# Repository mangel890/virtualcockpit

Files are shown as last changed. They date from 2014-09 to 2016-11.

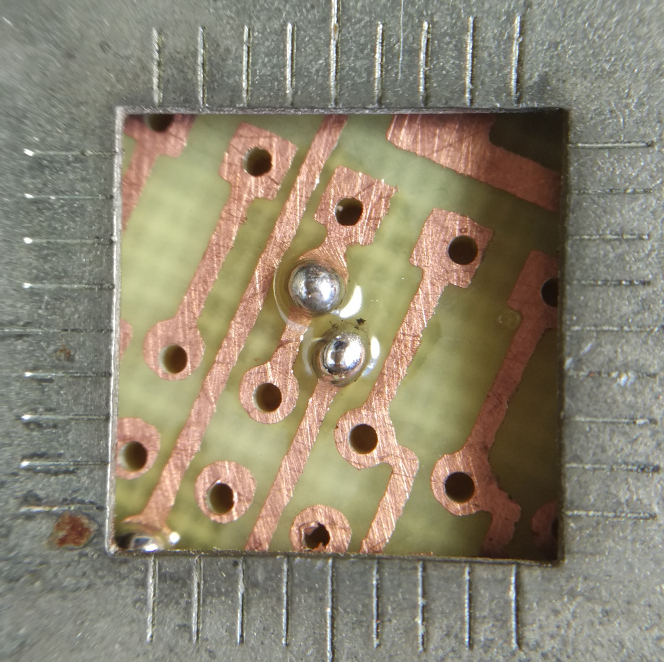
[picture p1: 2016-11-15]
images/ard4.jpg

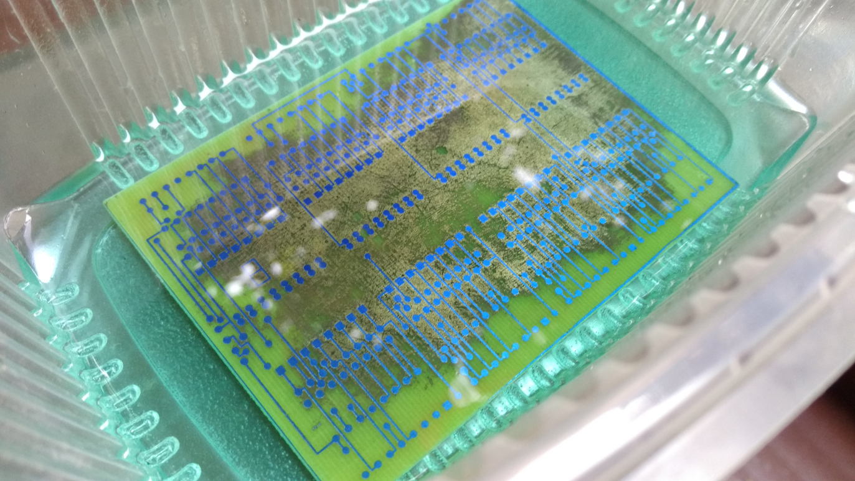
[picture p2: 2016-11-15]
images/ard2.jpg

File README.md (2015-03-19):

# virtualcockpit
Virtual Boeing 737 Cockpit

This is a project to build my own Boeing 737 cockpit
It is based on Arduino and Flight Simulator

This is on early stages now, many more changes are needed

Arduino/ contains a arduino .ino file for the MCP of the 737

CNC/ Sketch developed for my CNC that helps drilling the panels

PCB/ Different boards developed for extending input and output in Arduino Mega

Drawings/ Sketch developed for printing the MCP of the 737

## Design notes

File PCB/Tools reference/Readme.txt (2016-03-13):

Use Inkscape
Save in .dxf unchecking ROBO-Master and LWPolyline output types
Open file in DXF2GCODE: https://sourceforge.net/projects/dxf2gcode/?source=typ_redirect
Export: Optimize and convert (make sure you modify the z levels so that it only mills at one level)
Open in Basic3DViewer

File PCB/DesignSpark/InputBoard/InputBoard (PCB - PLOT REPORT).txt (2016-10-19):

PLOT REPORT
-----------

Report File:        C:\repo\PCB\DesignSpark\InputBoard\InputBoard (PCB - PLOT REPORT).txt
Report Written:     Wednesday, October 19, 2016
Project Path:       C:\repo\PCB\DesignSpark\InputBoard\InputBoard.prj
Design Path:        C:\repo\PCB\DesignSpark\InputBoard\InputBoard.pcb
Design Title:       
Created:            28/03/2015 19:30:17
Last Saved:         19/10/2016 20:01:03
Editing Time:       784 min
Units:              mm (precision 1)

Device Settings
===============

Windows Settings
================

    Printer 'Bullzip PDF Printer'
    Copies: 1

Plots Output
============

    Plot Job: "C:\repo\PCB\DesignSpark\InputBoard\InputBoard.mop"

Windows Output
==============

    Layers:
    -----------------
    Bottom Copper

End Of Report.

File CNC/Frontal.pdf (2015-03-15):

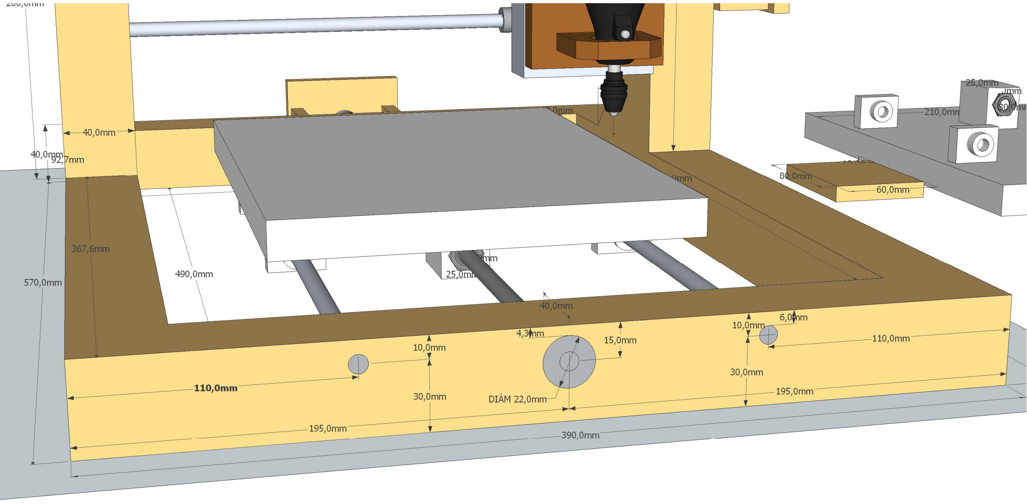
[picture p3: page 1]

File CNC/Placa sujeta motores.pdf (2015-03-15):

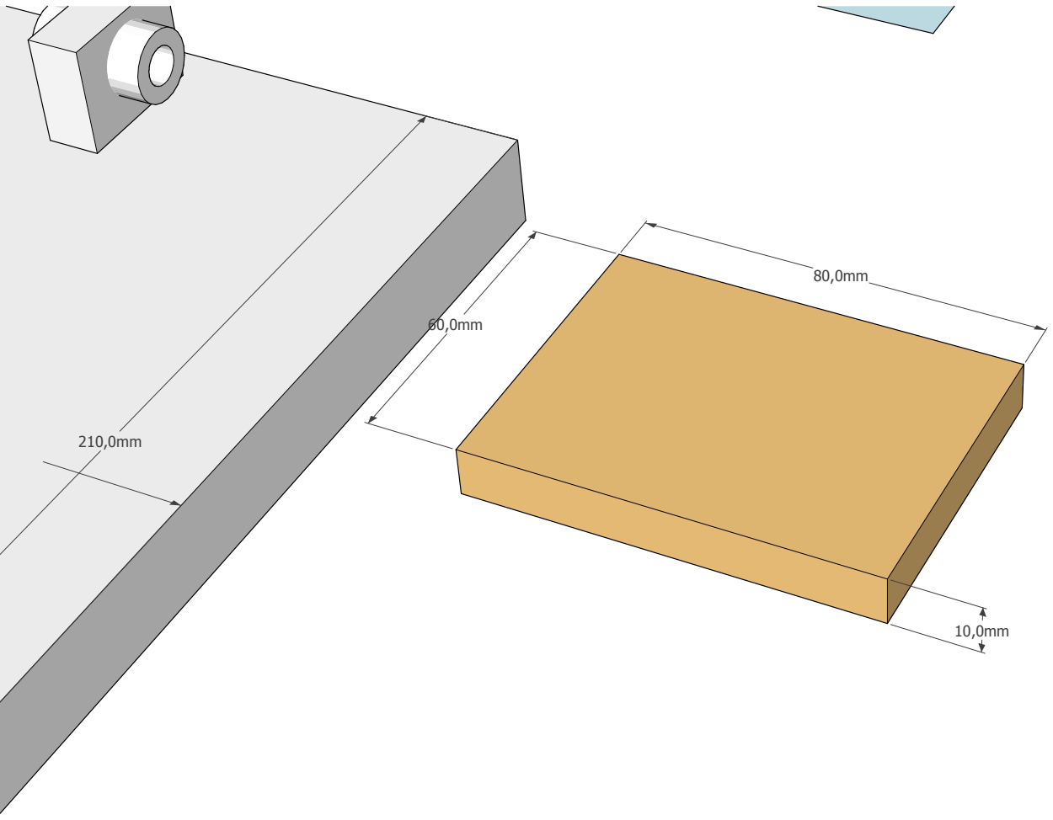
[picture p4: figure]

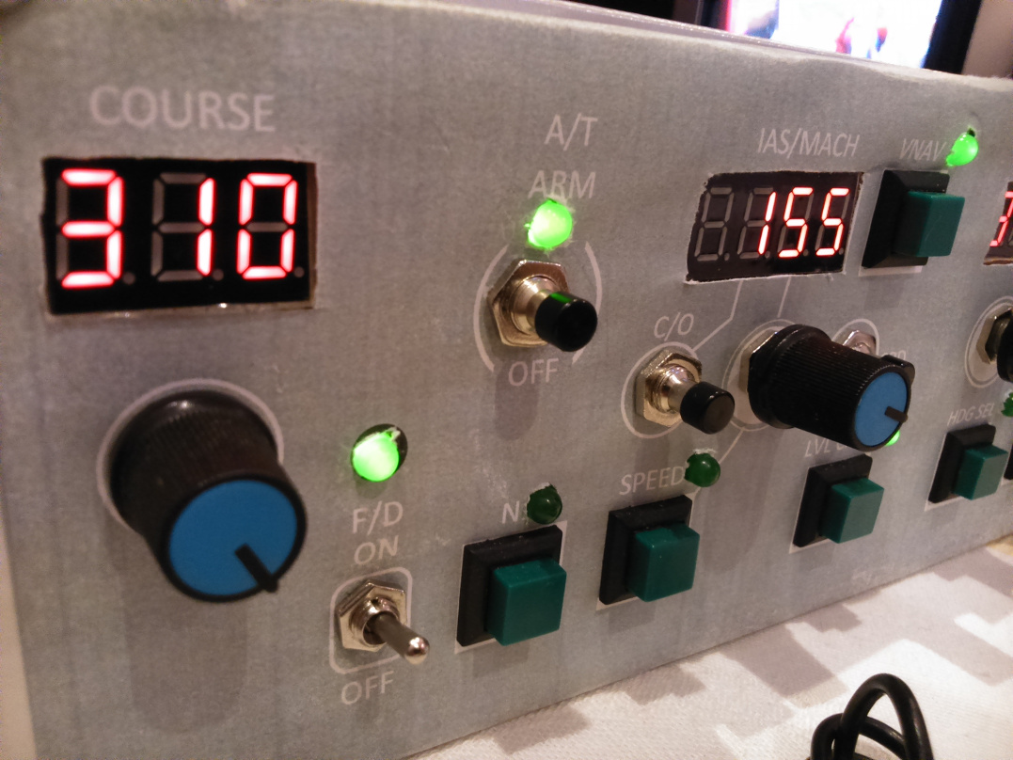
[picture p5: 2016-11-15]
images/mcp1.jpg

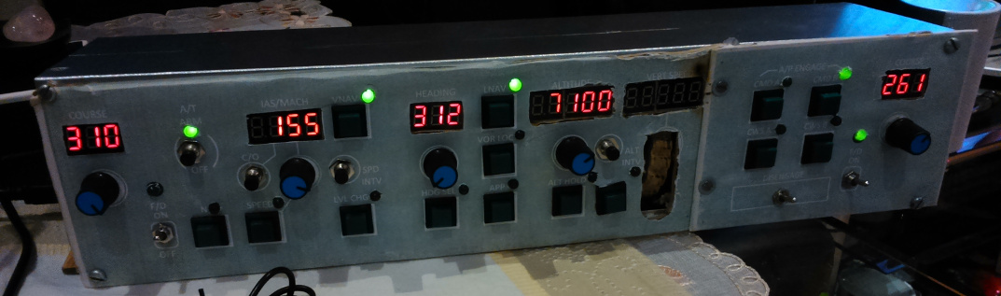
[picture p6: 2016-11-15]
images/mcp3.jpg

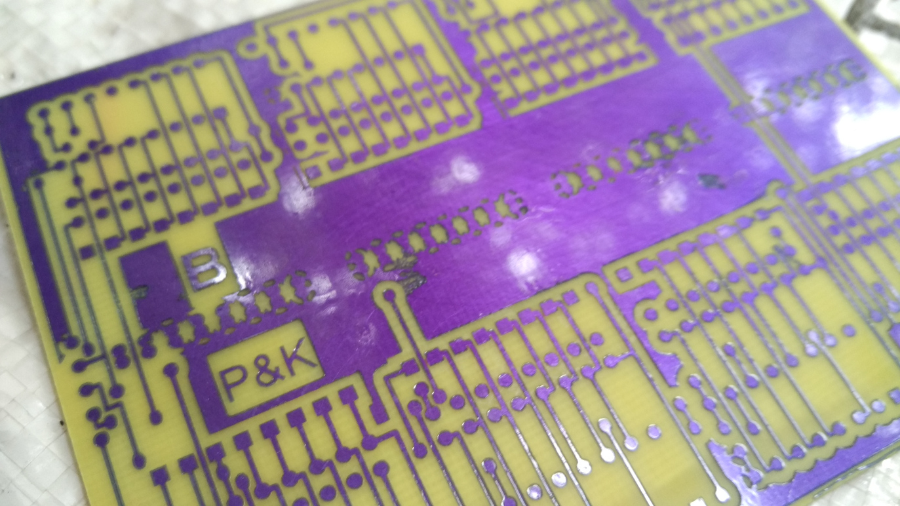
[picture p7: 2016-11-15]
images/ard3.jpg

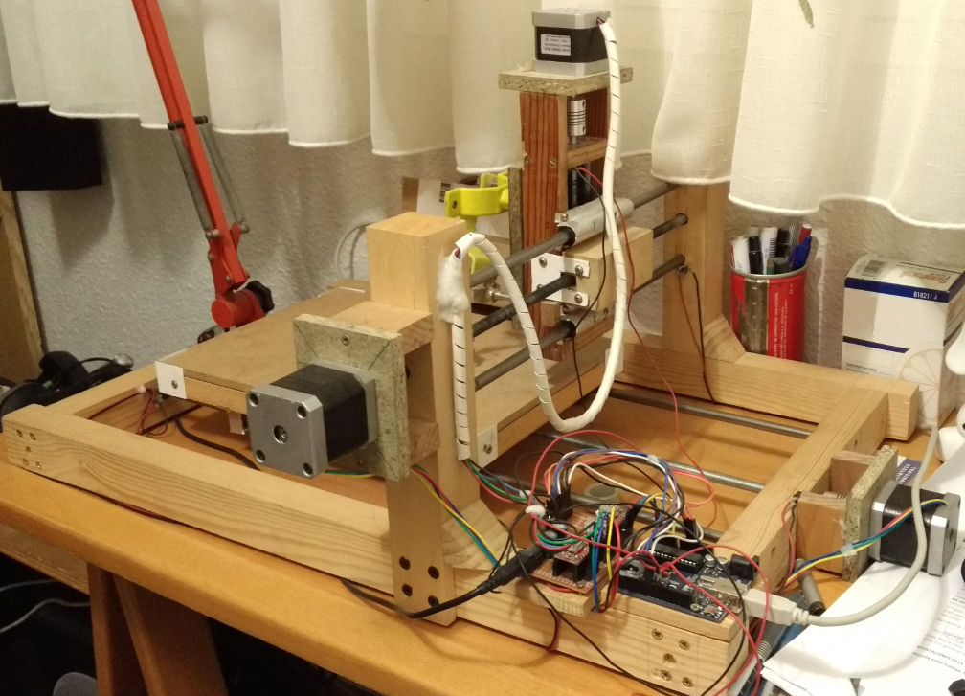
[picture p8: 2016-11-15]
images/cnc1.jpg

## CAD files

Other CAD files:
CNC/Sketch.skp

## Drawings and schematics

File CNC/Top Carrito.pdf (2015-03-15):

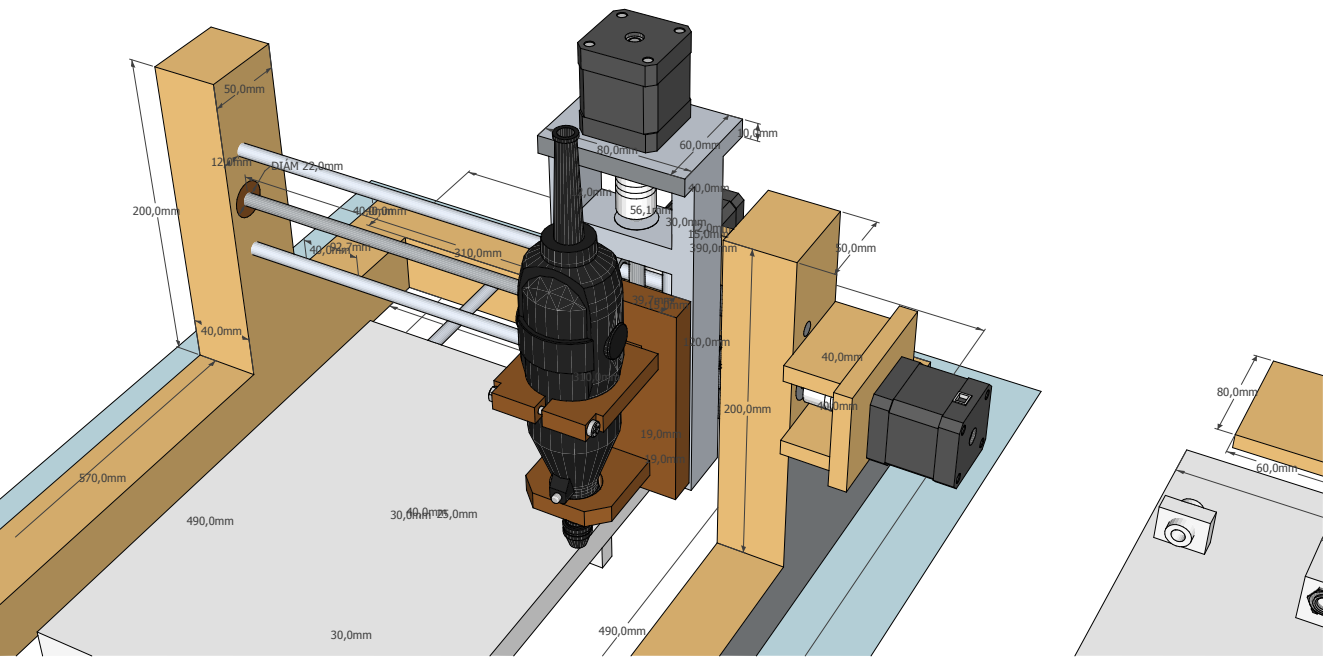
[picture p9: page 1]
DIÁM 22,0mm

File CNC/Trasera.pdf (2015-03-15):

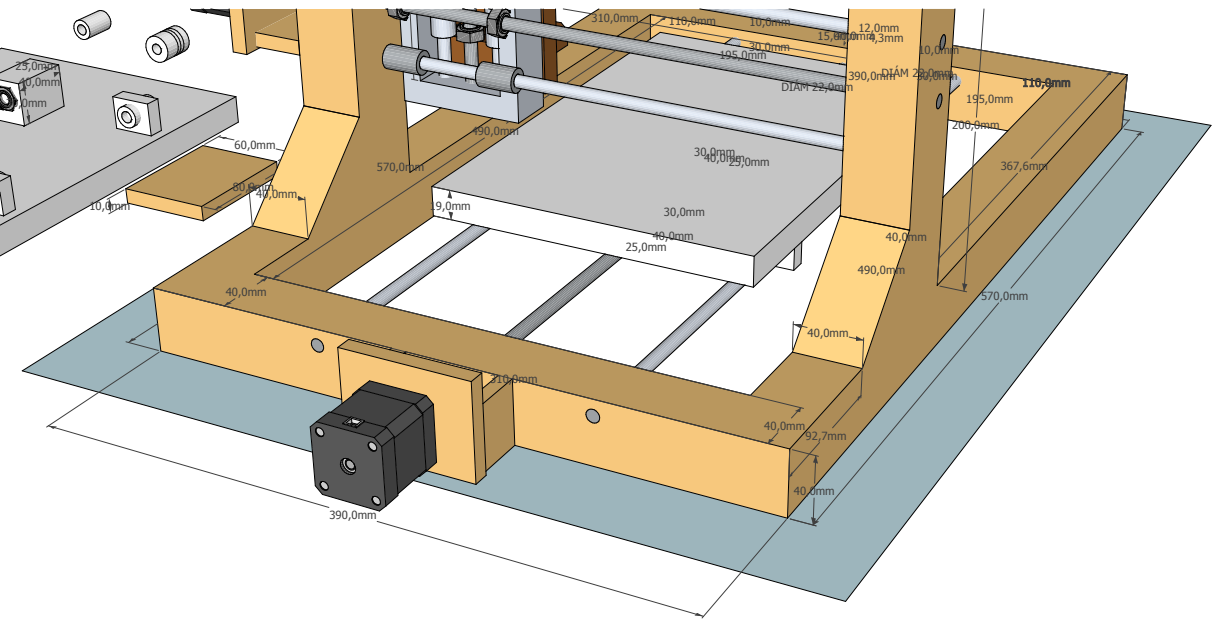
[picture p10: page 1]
DIÁM 22,0mm

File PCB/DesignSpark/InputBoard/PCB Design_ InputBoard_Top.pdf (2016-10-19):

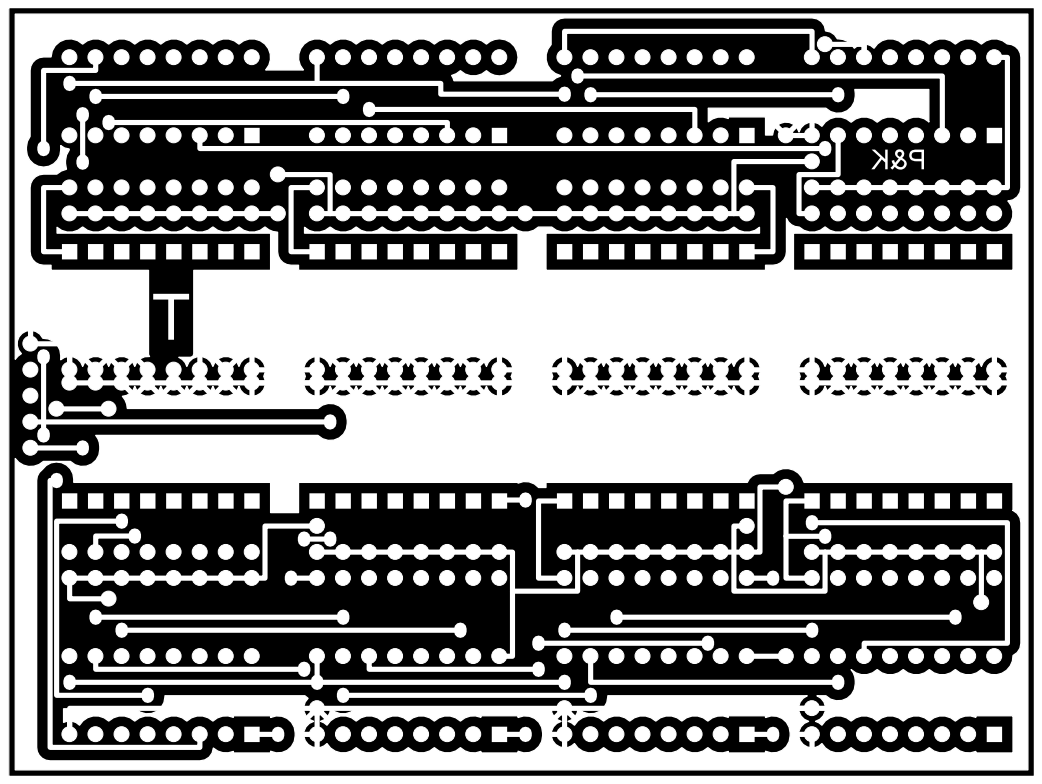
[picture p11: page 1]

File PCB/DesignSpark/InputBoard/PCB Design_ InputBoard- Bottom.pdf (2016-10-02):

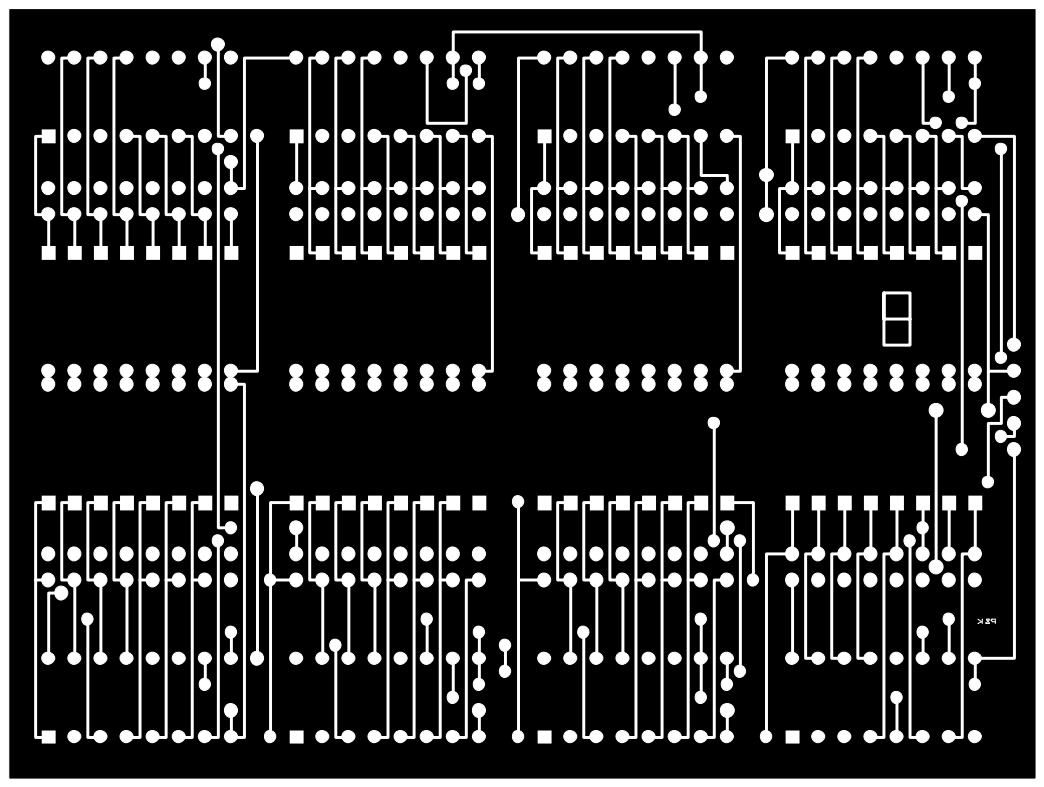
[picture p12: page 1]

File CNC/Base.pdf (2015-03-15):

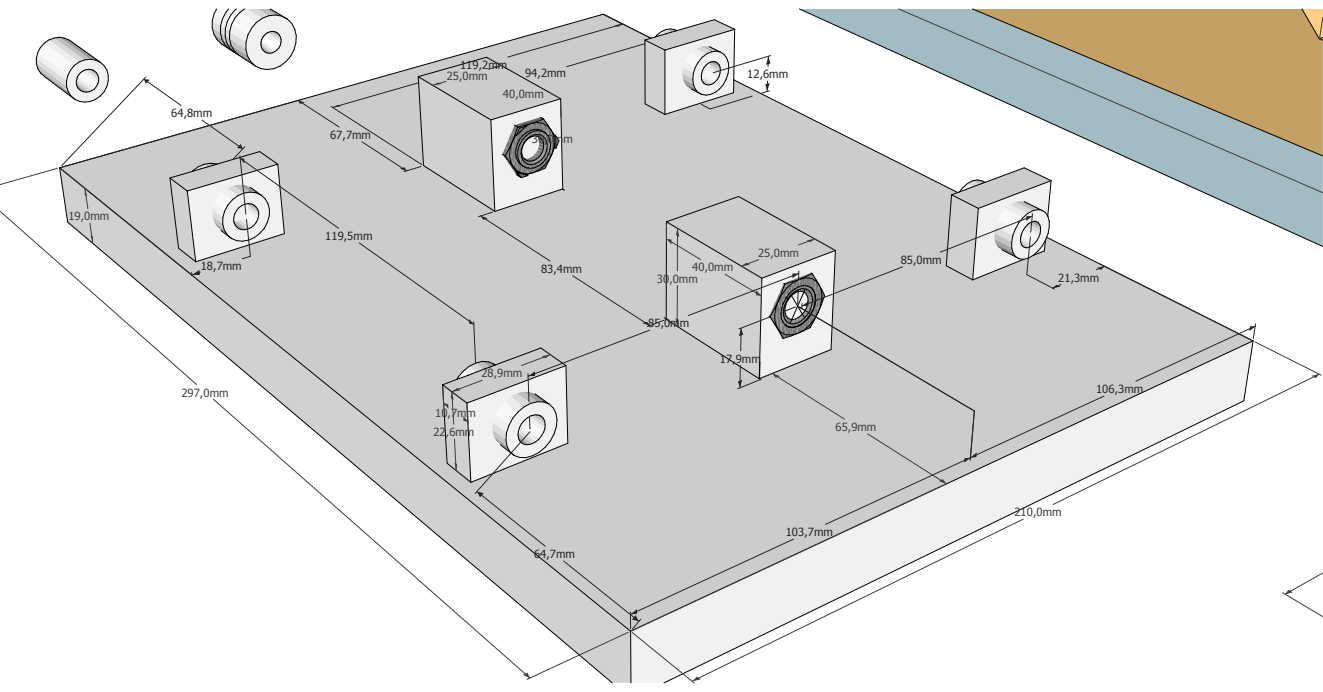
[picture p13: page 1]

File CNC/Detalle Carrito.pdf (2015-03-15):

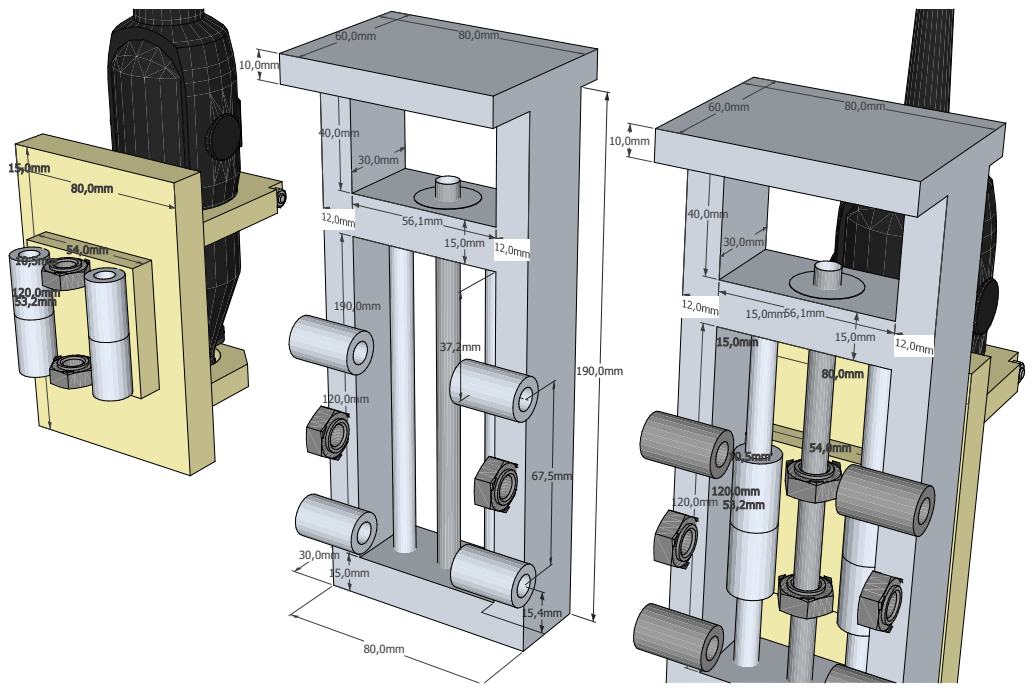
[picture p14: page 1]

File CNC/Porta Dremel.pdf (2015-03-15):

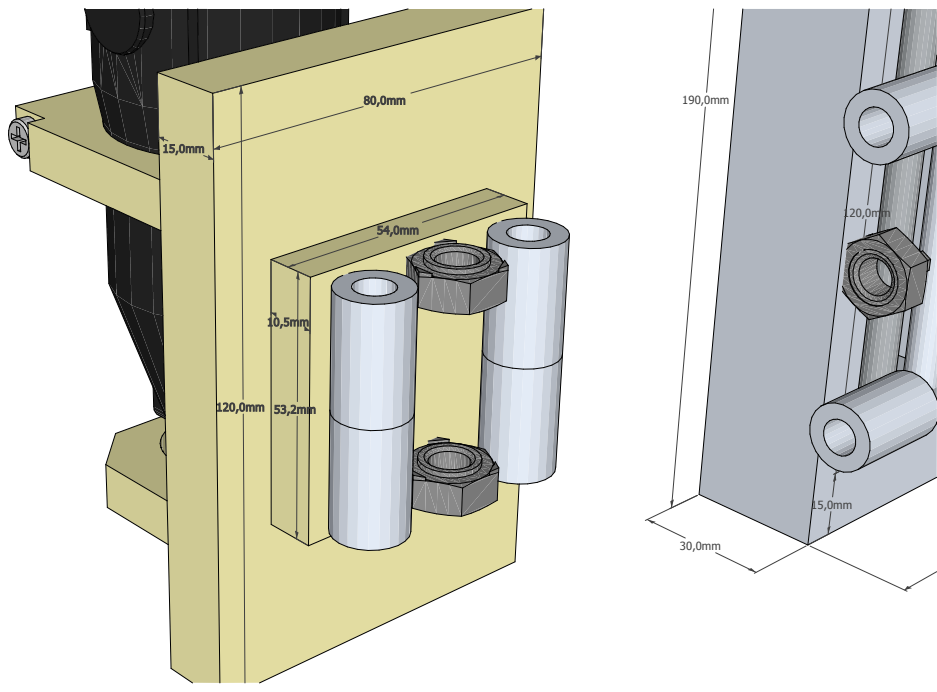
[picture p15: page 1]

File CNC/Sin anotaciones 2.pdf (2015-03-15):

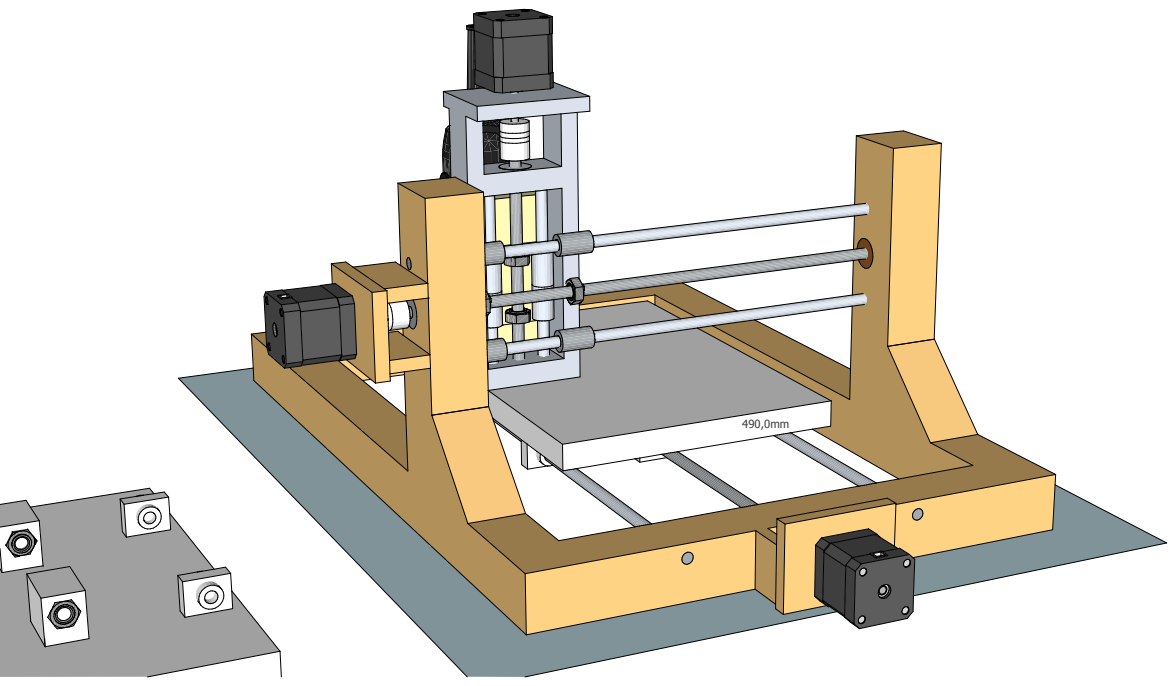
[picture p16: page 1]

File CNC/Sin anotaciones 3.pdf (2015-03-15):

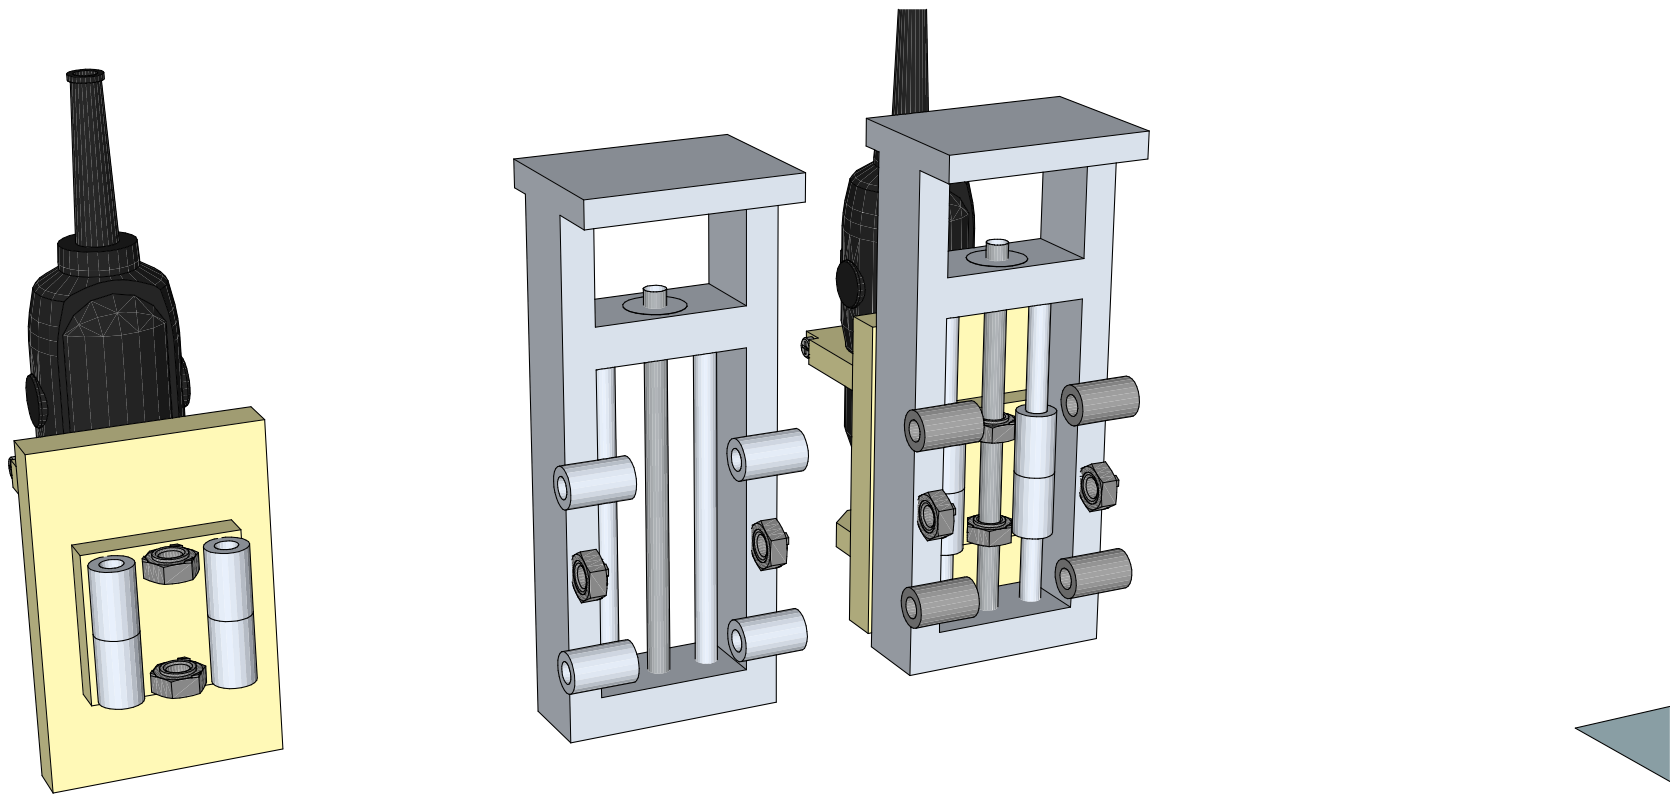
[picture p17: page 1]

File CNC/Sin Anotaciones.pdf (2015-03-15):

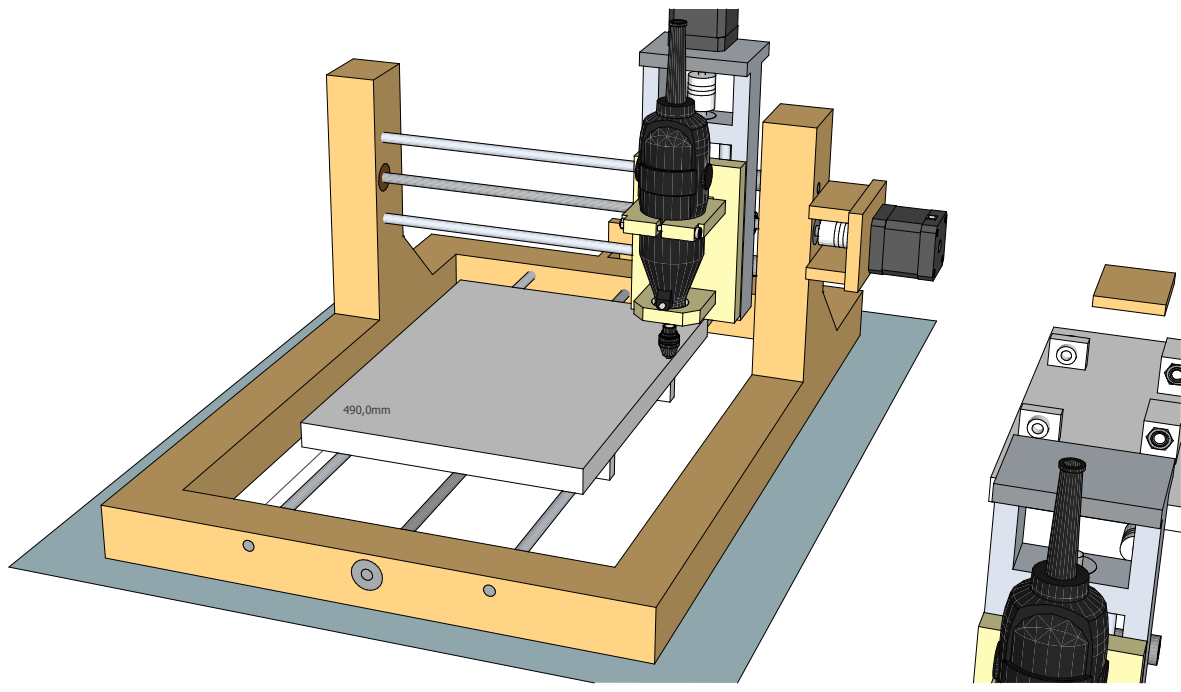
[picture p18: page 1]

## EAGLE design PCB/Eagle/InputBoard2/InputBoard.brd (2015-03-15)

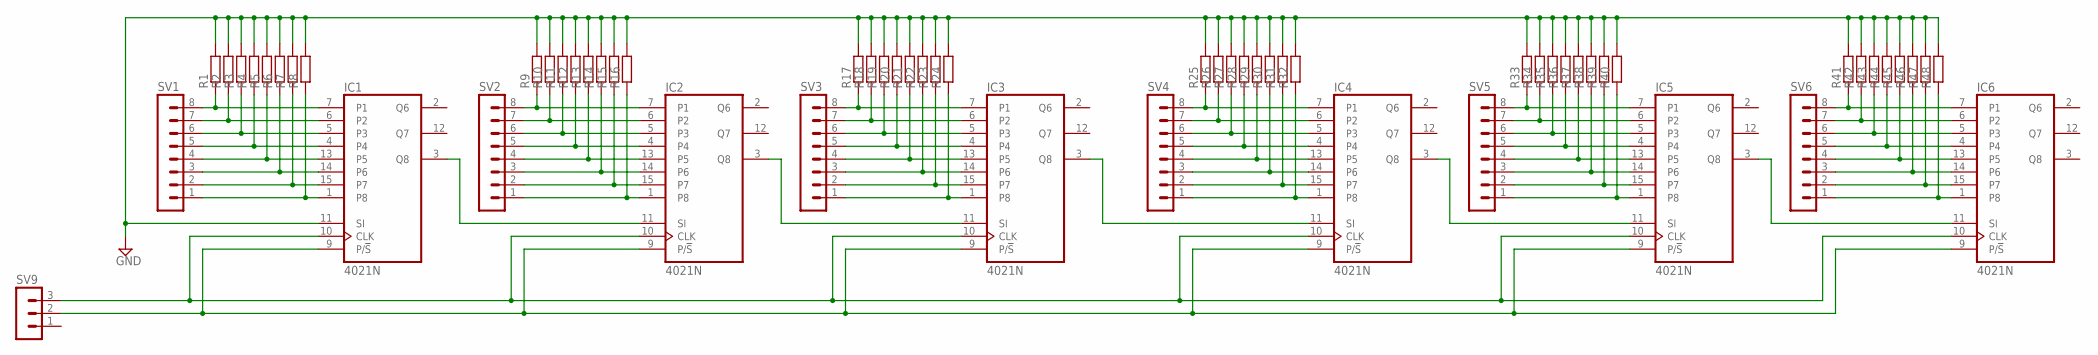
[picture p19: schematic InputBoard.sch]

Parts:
IC1, IC2, IC3, IC4, IC5, IC6: 4021N; DIL16
R1, R2, R3, R4, R5, R6, R7, R8, R9, R10, R11, R12, R13, R14, R15, R16, R17, R18, R19, R20, R21, R22, R23, R24, R25, R26, R27, R28, R29, R30, R31, R32, R33, R34, R35, R36, R37, R38, R39, R40, R41, R42, R43, R44, R45, R46, R47, R48: R-EU_0207/10; 0207/10
SV1, SV2, SV3, SV4, SV5, SV6: MA08-1
SV9: MA03-1

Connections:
GND: IC1.11 (SI), IC3.3 (Q8), IC4.11 (SI), R1.2, R2.2, R3.2, R4.2, R5.2, R6.2, R7.2, R8.2, R9.2, R10.2, R11.2, R12.2, R13.2, R14.2, R15.2, R16.2, R17.2, R18.2, R19.2, R20.2, R21.2, R22.2, R23.2, R24.2, R25.2, R26.2, R27.2, R28.2, R29.2, R30.2, R31.2, R32.2, R33.2, R34.2, R35.2, R36.2, R37.2, R38.2, R39.2, R40.2, R41.2, R42.2, R43.2, R44.2, R45.2, R46.2, R47.2, R48.2
unnamed: IC4.7 (P1), R25.1, SV4.8
unnamed: IC1.10 (CLK), IC2.10 (CLK), IC3.10 (CLK), IC4.10 (CLK), IC5.10 (CLK), IC6.10 (CLK), SV9.3
unnamed: IC1.3 (Q8), IC2.11 (SI)
unnamed: IC2.7 (P1), R9.1, SV2.8
unnamed: IC4.5 (P3), R27.1, SV4.6
unnamed: IC2.5 (P3), R11.1, SV2.6
unnamed: IC2.4, R12.1, SV2.5
unnamed: IC2.13 (P5), R13.1, SV2.4
unnamed: IC2.14 (P6), R14.1, SV2.3
unnamed: IC1.7 (P1), R1.1, SV1.8
unnamed: IC1.6 (P2), R2.1, SV1.7
unnamed: IC1.5 (P3), R3.1, SV1.6
unnamed: IC1.4, R4.1, SV1.5
unnamed: IC1.13 (P5), R5.1, SV1.4
unnamed: IC1.14 (P6), R6.1, SV1.3
unnamed: IC1.15 (P7), R7.1, SV1.2
unnamed: IC1.1 (P8), R8.1, SV1.1
unnamed: IC2.15 (P7), R15.1, SV2.2
unnamed: IC2.6 (P2), R10.1, SV2.7
unnamed: IC2.1 (P8), R16.1, SV2.1
unnamed: IC3.7 (P1), R17.1, SV3.8
unnamed: IC3.5 (P3), R19.1, SV3.6
unnamed: IC1.9 (P/!S), IC2.9 (P/!S), IC3.9 (P/!S), IC4.9 (P/!S), IC5.9 (P/!S), IC6.9 (P/!S), SV9.2
unnamed: IC3.4, R20.1, SV3.5
unnamed: IC3.13 (P5), R21.1, SV3.4
unnamed: IC3.14 (P6), R22.1, SV3.3
unnamed: IC3.15 (P7), R23.1, SV3.2
unnamed: IC3.6 (P2), R18.1, SV3.7
unnamed: IC3.1 (P8), R24.1, SV3.1
unnamed: IC4.4, R28.1, SV4.5
unnamed: IC2.3 (Q8), IC3.11 (SI)
unnamed: IC4.13 (P5), R29.1, SV4.4
unnamed: IC4.14 (P6), R30.1, SV4.3
unnamed: IC4.15 (P7), R31.1, SV4.2
unnamed: IC4.6 (P2), R26.1, SV4.7
unnamed: IC4.1 (P8), R32.1, SV4.1
unnamed: IC5.7 (P1), R33.1, SV5.8
unnamed: IC5.5 (P3), R35.1, SV5.6
unnamed: IC5.4, R36.1, SV5.5
unnamed: IC5.13 (P5), R37.1, SV5.4
unnamed: IC5.14 (P6), R38.1, SV5.3
unnamed: IC5.15 (P7), R39.1, SV5.2
unnamed: IC5.6 (P2), R34.1, SV5.7
unnamed: IC5.1 (P8), R40.1, SV5.1
unnamed: IC4.3 (Q8), IC5.11 (SI)
unnamed: IC6.7 (P1), R41.1, SV6.8
unnamed: IC6.5 (P3), R43.1, SV6.6
unnamed: IC6.4, R44.1, SV6.5
unnamed: IC6.13 (P5), R45.1, SV6.4
unnamed: IC6.14 (P6), R46.1, SV6.3
unnamed: IC6.15 (P7), R47.1, SV6.2
unnamed: IC6.6 (P2), R42.1, SV6.7
unnamed: IC6.1 (P8), R48.1, SV6.1
unnamed: IC5.3 (Q8), IC6.11 (SI)
VDD: IC1.16 (VDD), IC2.16 (VDD), IC3.16 (VDD), IC4.16 (VDD), IC5.16 (VDD), IC6.16 (VDD)
VSS: IC1.8 (VSS), IC2.8 (VSS), IC3.8 (VSS), IC4.8 (VSS), IC5.8 (VSS), IC6.8 (VSS)

Board: 2 copper layers, 61 parts (0 on the bottom side), 57 nets, no tracks yet.

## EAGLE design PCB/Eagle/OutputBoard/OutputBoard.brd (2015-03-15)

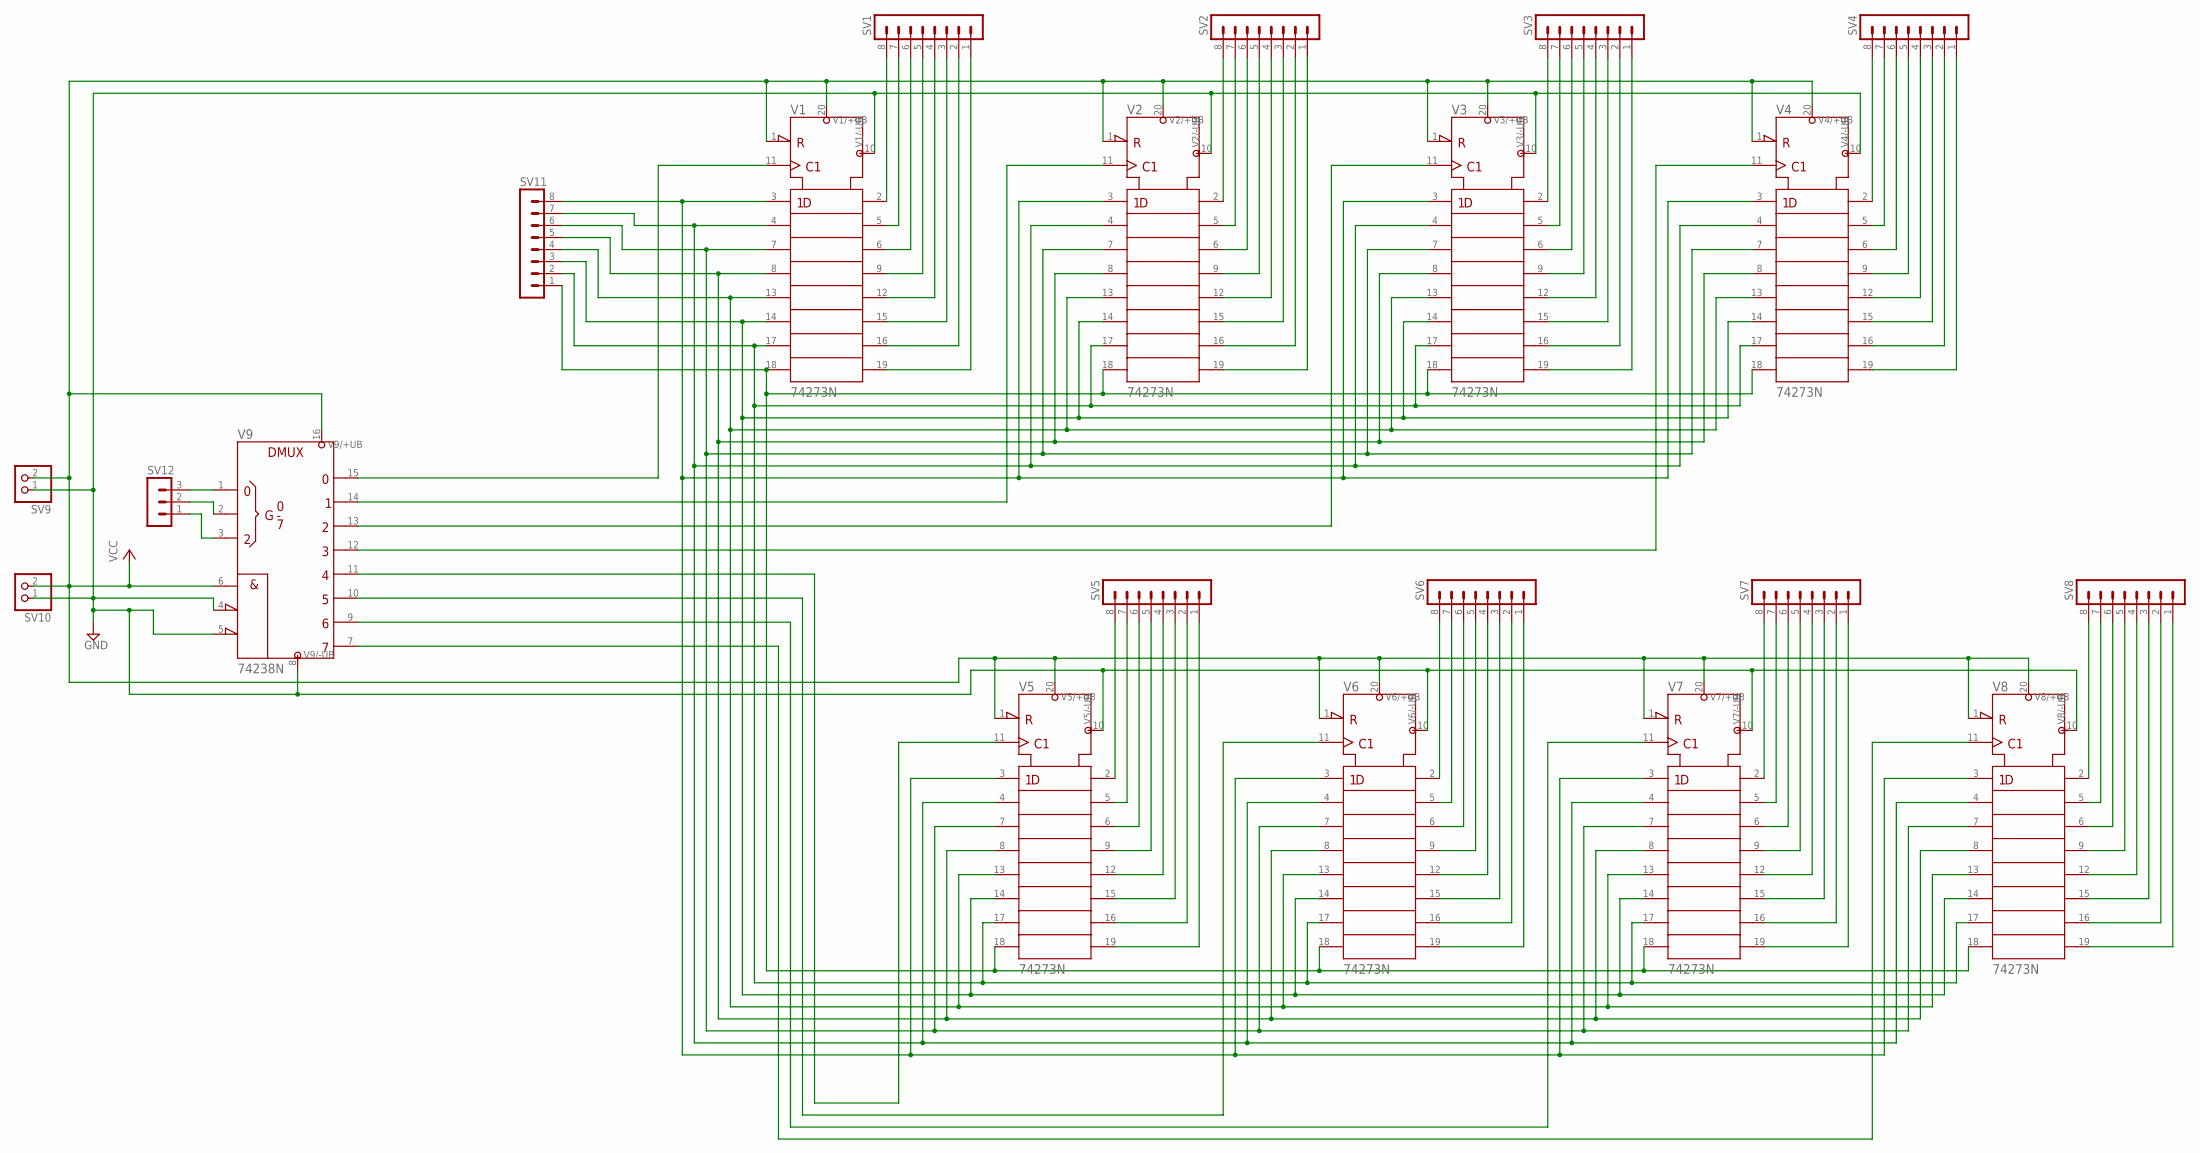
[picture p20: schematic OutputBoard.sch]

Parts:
SV1, SV2, SV3, SV4, SV5, SV6, SV7, SV8, SV11: MA08-1
SV9, SV10: PINHD-1X2; 1X02
SV12: MA03-1
V1, V2, V3, V4, V5, V6, V7, V8: 74273N; DIL20
V9: 74238N; DIL16

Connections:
BUS1: SV11.8, V1.3 (1D), V2.3 (1D), V3.3 (1D), V4.3 (1D), V5.3 (1D), V6.3 (1D), V7.3 (1D), V8.3 (1D)
DATA1: SV11.1, V1.18 (8D), V2.18 (8D), V3.18 (8D), V4.18 (8D), V5.18 (8D), V6.18 (8D), V7.18 (8D), V8.18 (8D)
DATA2: SV11.2, V1.17 (7D), V2.17 (7D), V3.17 (7D), V4.17 (7D), V5.17 (7D), V6.17 (7D), V7.17 (7D), V8.17 (7D)
DATA3: SV11.3, V1.14 (6D), V2.14 (6D), V3.14 (6D), V4.14 (6D), V5.14 (6D), V6.14 (6D), V7.14 (6D), V8.14 (6D)
DATA8: SV11.4, V1.13 (5D), V2.13 (5D), V3.13 (5D), V4.13 (5D), V5.13 (5D), V6.13 (5D), V7.13 (5D), V8.13 (5D)
GND: SV9.1, SV10.1, V1.10 (-UB), V2.10 (-UB), V3.10 (-UB), V4.10 (-UB), V5.10 (-UB), V6.10 (-UB), V7.10 (-UB), V8.10 (-UB), V9.4 (!G2A), V9.5 (!G2B), V9.8 (-UB)
unnamed: V3.11 (CLK), V9.13 (Y2)
unnamed: SV2.8, V2.2 (1Q)
unnamed: V1.11 (CLK), V9.15 (Y0)
unnamed: V2.11 (CLK), V9.14 (Y1)
unnamed: SV2.7, V2.5 (2Q)
unnamed: SV2.6, V2.6 (3Q)
unnamed: SV2.5, V2.9 (4Q)
unnamed: SV2.4, V2.12 (5Q)
unnamed: SV2.3, V2.15 (6Q)
unnamed: SV2.2, V2.16 (7Q)
unnamed: SV2.1, V2.19 (8Q)
unnamed: SV1.8, V1.2 (1Q)
unnamed: SV12.2, V9.2 (B)
unnamed: SV12.1, V9.3 (C)
unnamed: SV5.8, V5.2 (1Q)
unnamed: SV1.7, V1.5 (2Q)
unnamed: SV1.6, V1.6 (3Q)
unnamed: SV1.5, V1.9 (4Q)
unnamed: SV1.4, V1.12 (5Q)
unnamed: SV12.3, V9.1 (A)
unnamed: SV5.7, V5.5 (2Q)
unnamed: SV5.6, V5.6 (3Q)
unnamed: SV1.3, V1.15 (6Q)
unnamed: SV1.2, V1.16 (7Q)
unnamed: SV1.1, V1.19 (8Q)
unnamed: V4.11 (CLK), V9.12 (Y3)
unnamed: V5.11 (CLK), V9.11 (Y4)
unnamed: V6.11 (CLK), V9.10 (Y5)
unnamed: SV11.7, V1.4 (2D), V2.4 (2D), V3.4 (2D), V4.4 (2D), V5.4 (2D), V6.4 (2D), V7.4 (2D), V8.4 (2D)
unnamed: SV3.8, V3.2 (1Q)
unnamed: SV3.7, V3.5 (2Q)
unnamed: SV3.6, V3.6 (3Q)
unnamed: SV3.5, V3.9 (4Q)
unnamed: SV3.4, V3.12 (5Q)
unnamed: SV3.3, V3.15 (6Q)
unnamed: SV3.2, V3.16 (7Q)
unnamed: SV3.1, V3.19 (8Q)
unnamed: SV4.8, V4.2 (1Q)
unnamed: SV4.7, V4.5 (2Q)
unnamed: SV4.6, V4.6 (3Q)
unnamed: SV4.5, V4.9 (4Q)
unnamed: SV4.4, V4.12 (5Q)
unnamed: SV4.3, V4.15 (6Q)
unnamed: SV4.2, V4.16 (7Q)
unnamed: SV4.1, V4.19 (8Q)
unnamed: SV11.6, V1.7 (3D), V2.7 (3D), V3.7 (3D), V4.7 (3D), V5.7 (3D), V6.7 (3D), V7.7 (3D), V8.7 (3D)
unnamed: SV11.5, V1.8 (4D), V2.8 (4D), V3.8 (4D), V4.8 (4D), V5.8 (4D), V6.8 (4D), V7.8 (4D), V8.8 (4D)
unnamed: SV6.8, V6.2 (1Q)
unnamed: SV6.7, V6.5 (2Q)
unnamed: SV6.6, V6.6 (3Q)
unnamed: SV6.5, V6.9 (4Q)
unnamed: SV6.4, V6.12 (5Q)
unnamed: SV6.3, V6.15 (6Q)
unnamed: SV6.2, V6.16 (7Q)
unnamed: SV6.1, V6.19 (8Q)
unnamed: SV7.8, V7.2 (1Q)
unnamed: SV7.7, V7.5 (2Q)
unnamed: SV7.6, V7.6 (3Q)
unnamed: SV7.5, V7.9 (4Q)
unnamed: SV7.4, V7.12 (5Q)
unnamed: SV7.3, V7.15 (6Q)
unnamed: SV7.2, V7.16 (7Q)
unnamed: SV7.1, V7.19 (8Q)
unnamed: V7.11 (CLK), V9.9 (Y6)
unnamed: SV8.8, V8.2 (1Q)
unnamed: SV8.7, V8.5 (2Q)
unnamed: SV8.6, V8.6 (3Q)
unnamed: SV8.5, V8.9 (4Q)
unnamed: SV8.4, V8.12 (5Q)
unnamed: SV8.3, V8.15 (6Q)
unnamed: SV8.2, V8.16 (7Q)
unnamed: SV8.1, V8.19 (8Q)
unnamed: SV5.5, V5.9 (4Q)
unnamed: SV5.4, V5.12 (5Q)
unnamed: SV5.3, V5.15 (6Q)
unnamed: SV5.2, V5.16 (7Q)
unnamed: SV5.1, V5.19 (8Q)
unnamed: V8.11 (CLK), V9.7 (Y7)
VCC: SV9.2, SV10.2, V1.1 (!CLR), V1.20 (+UB), V2.1 (!CLR), V2.20 (+UB), V3.1 (!CLR), V3.20 (+UB), V4.1 (!CLR), V4.20 (+UB), V5.1 (!CLR), V5.20 (+UB), V6.1 (!CLR), V6.20 (+UB), V7.1 (!CLR), V7.20 (+UB), V8.1 (!CLR), V8.20 (+UB), V9.6 (G1), V9.16 (+UB)

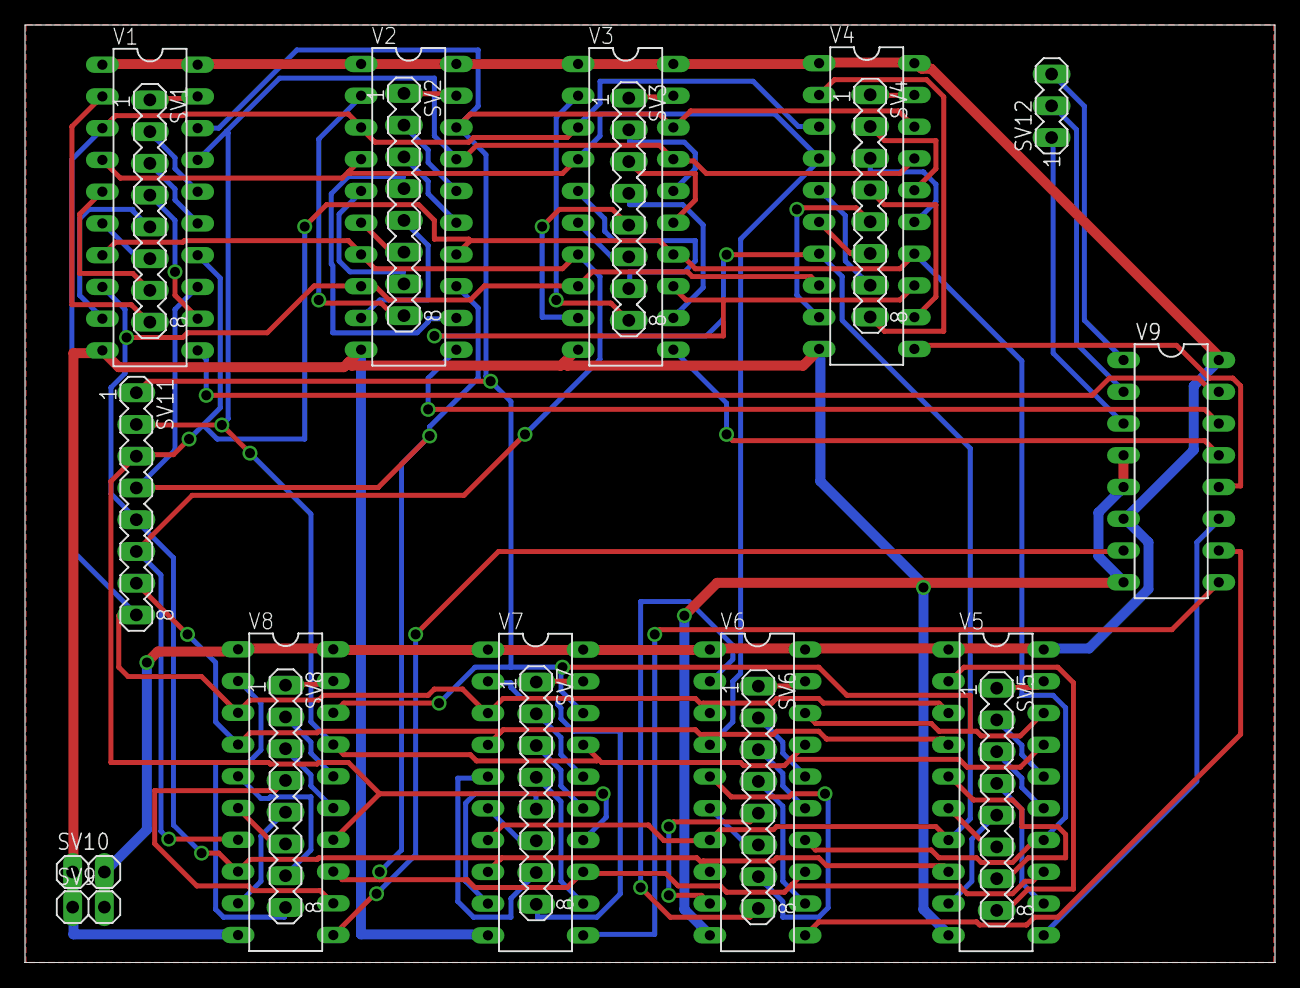
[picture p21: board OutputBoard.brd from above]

Board: 2 copper layers, 100.0 x 75.0 mm, 21 parts (0 on the bottom side), 85 nets.

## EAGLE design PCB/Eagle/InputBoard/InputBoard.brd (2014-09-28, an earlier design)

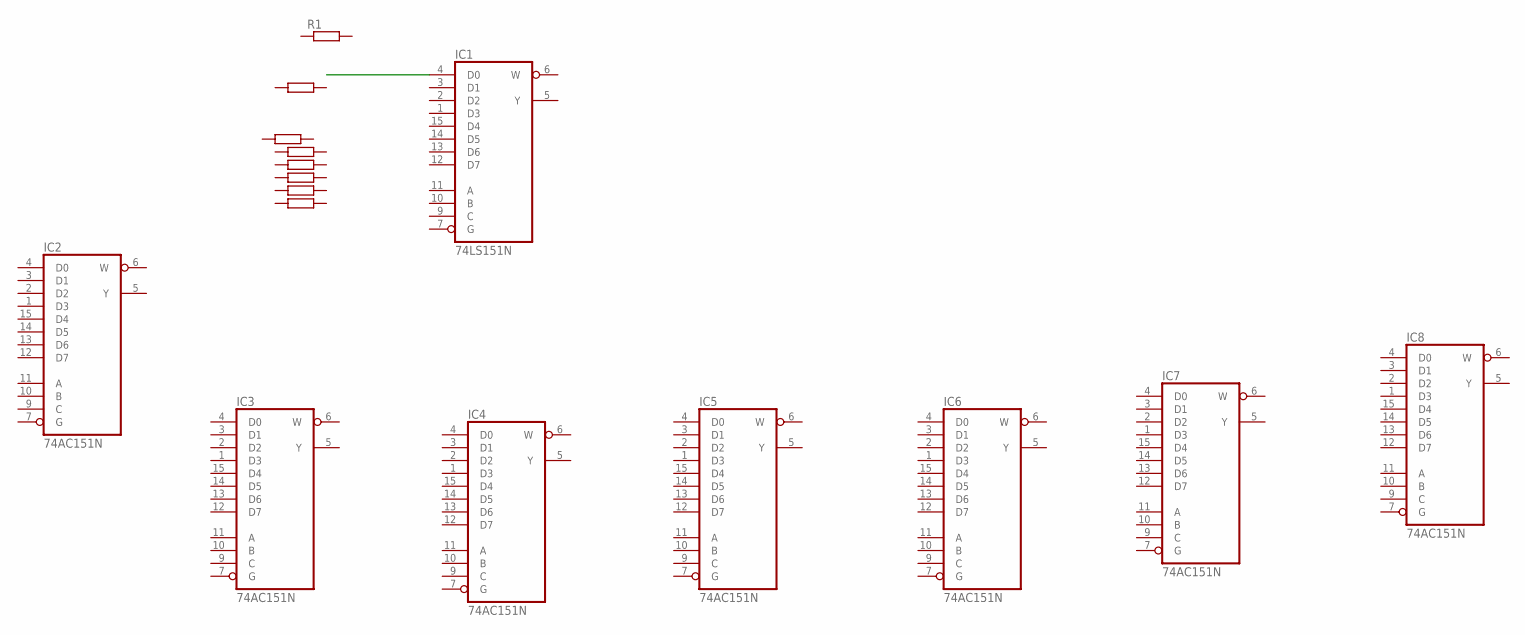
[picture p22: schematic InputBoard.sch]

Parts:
IC1: 74LS151N; DIL16
IC2, IC3, IC4, IC5, IC6, IC7, IC8: 74AC151N; DIL16
R1: R-EU_0207/10; 0207/10

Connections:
GND: IC1.8 (GND), IC2.8 (GND), IC3.8 (GND), IC4.8 (GND), IC5.8 (GND), IC6.8 (GND), IC7.8 (GND), IC8.8 (GND)
VCC: IC1.16 (VCC), IC2.16 (VCC), IC3.16 (VCC), IC4.16 (VCC), IC5.16 (VCC), IC6.16 (VCC), IC7.16 (VCC), IC8.16 (VCC)

Board: 2 copper layers, 9 parts (0 on the bottom side), 2 nets, no tracks yet.

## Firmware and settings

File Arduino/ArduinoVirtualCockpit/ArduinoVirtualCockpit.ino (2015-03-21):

//Input pin identifiers for rotary encoders (A down B up) 

const int PCRS1A = 2;
const int PCRS1B = 3;
const int PIASA = 4;
const int PIASB = 5;
const int PHDGA = 6;
const int PHDGB = 7;
const int PALTA = 8;
const int PALTB = 9;
const int PVSPA = 10;
const int PVSPB = 11;
const int PCRS2A = 12;
const int PCRS2B = 13;

//Output pin identifiers for the led selector (5 pins to select 32 leds and an enabler to switch on/off)
//Note this is also used for selecting the 7 segment displays  (up to 32)
const int PDSP0 = 40;
const int PDSP1 = 41;
const int PDSP2 = 42;
const int PDSP3 = 43;
const int PDSP4 = 44;
const int PDSP5 = 45;
const int PENBL = 38;

//Output pin identifiers for the 7 segments leds (note each display is selected with the above pins)
const int PSEGA = 53;
const int PSEGB = 51;
const int PSEGC = 49;
const int PSEGD = 47;
const int PSEGE = 46;
const int PSEGF = 52;
const int PSEGG = 50;
const int PSEGDP = 48;

//Input pin identifiers for switches
const int PSWATARM = 22;
const int PSWN1 = 24;
const int PSWCO = 26;
const int PSWSPEED = 28;
const int PSWVNAV = 30;
const int PSWSPDINTV = 32;
const int PSWLVLCHG = 34;
const int PSWHDG = 36;
const int PSWLNAV = 23;
const int PSWVORLOC = 25;
const int PSWAPP = 27;
const int PSWALTHOLD = 29;
const int PSWALTINTV = 31;
const int PSWVS = 33;
const int PSWCMDA = 35;
const int PSWCWSA = 37;
const int PSWDISENGAGE = 39;
const int PSWCMDB = 15;
const int PSWCWSB = 16;
const int PSWFD1 = 14;
const int PSWFD2 = 17;

int x, a, b, c, d, e, f;

int persistencyCte = 100; //100 recommended

//*********
// Displays
//*********
const int numberOfDisplays = 23;
const int segmentDisplay[18][7] = {{0, 0, 0, 0, 0, 0, 1}, //0
  {1, 0, 0, 1, 1, 1, 1}, //1
  {0, 0, 1, 0, 0, 1, 0}, //2
  {0, 0, 0, 0, 1, 1, 0}, //3
  {1, 0, 0, 1, 1, 0, 0}, //4
  {0, 1, 0, 0, 1, 0, 0}, //5
  {0, 1, 0, 0, 0, 0, 0}, //6
  {0, 0, 0, 1, 1, 1, 1}, //7
  {0, 0, 0, 0, 0, 0, 0}, //8
  {0, 0, 0, 1, 1, 0, 0}, //9
  {0, 0, 0, 1, 0, 0, 0}, //10 = A
  {1, 1, 1, 1, 1, 1, 0}, //11 = b
  {1, 1, 1, 1, 1, 1, 0}, //12 = C
  {1, 1, 1, 1, 1, 1, 0}, //13 = d
  {1, 1, 1, 1, 1, 1, 0}, //14 = E
  {1, 1, 1, 1, 1, 1, 0}, //15 = F
  {1, 1, 1, 1, 1, 1, 1},  //16 = empty for showing just the point
  {1, 1, 1, 1, 1, 1, 0}, //17 = - hyphen, minus sign
};
class Displays
{

    int displayStatus[numberOfDisplays];

    int pinDisplay0M;
    int pinDisplay1M;
    int pinDisplay2M;
    int pinDisplay3M;
    int pinDisplay4M;
    int pinDisplay5M;
    int pinEnablerM;
    int pinValueAM;
    int pinValueBM;
    int pinValueCM;
    int pinValueDM;
    int pinValueEM;
    int pinValueFM;
    int pinValueGM;
    int pinValueDPM;

    bool iasBlankM;
    bool iasUnderspeedM;
    bool iasOverspeedM;
    bool vspdBlankM;

  public:

    // A ctor for defining a 7 segment display in the system
    // displayX: pins for selecting which display to activate
    // enabler: pin to switch it on/off
    // valueX: pin for the 7 segment led (A,B,C,D,E,F,G)
    Displays(int display0, int display1, int display2, int display3, int display4, int display5, int enabler,
             int valueA, int valueB, int valueC, int valueD, int valueE, int valueF, int valueG, int valueDP):
      pinDisplay0M(display0), pinDisplay1M(display1), pinDisplay2M(display2), pinDisplay3M(display3), pinDisplay4M(display4),
      pinDisplay5M(display5), pinEnablerM(enabler), pinValueAM(valueA), pinValueBM(valueB), pinValueCM(valueC), pinValueDM(valueD),
      pinValueEM(valueE), pinValueFM(valueF), pinValueGM(valueG), pinValueDPM(valueDP), iasBlankM(0), iasUnderspeedM(0),
      iasOverspeedM(0), vspdBlankM(0)
    {
      pinMode(pinDisplay0M, OUTPUT);
      pinMode(pinDisplay1M, OUTPUT);
      pinMode(pinDisplay2M, OUTPUT);
      pinMode(pinDisplay3M, OUTPUT);
      pinMode(pinDisplay4M, OUTPUT);
      pinMode(pinDisplay5M, OUTPUT);
      pinMode(pinEnablerM, OUTPUT);
      pinMode(pinValueAM, OUTPUT);
      pinMode(pinValueBM, OUTPUT);
      pinMode(pinValueCM, OUTPUT);
      pinMode(pinValueDM, OUTPUT);
      pinMode(pinValueEM, OUTPUT);
      pinMode(pinValueFM, OUTPUT);
      pinMode(pinValueGM, OUTPUT);
      pinMode(pinValueDPM, OUTPUT);

      for (int i = 0; i < numberOfDisplays; i++)
        displayStatus[i] = -1;
    }

    void setDisplay(const int displayNumber, const int value) //-1 to not display anything, *1000 to display point, 999 to display only point
    {
      displayStatus[displayNumber] = value;
    }

    void setDisplay(const char* command, const char* value) //4 chars for the command, 5 for the value
    {
      if (strcmp(command, "CRS1") == 0)
      {
        setDisplay(0, value[4] - '0');
        setDisplay(1, value[3] - '0');
        setDisplay(2, value[2] - '0');

      }
      else if (strcmp(command, "IASM") == 0)
      {
        setDisplay(3, value[4] - '0');
        setDisplay(4, value[3] - '0');
        if (value[2] == '.')

          setDisplay(5, 1016);

        else
          setDisplay(5, value[2] - '0');

      }
      else if (strcmp(command, "IASB") == 0)
      {
        iasBlankM = value[4] - '0';
      }
      else if (strcmp(command, "IASO") == 0)
      {
        iasOverspeedM = value[4] - '0';
        if (iasOverspeedM == 1)
          setDisplay(6, 8);
        else
          setDisplay(6, -1);
      }
      else if (strcmp(command, "IASU") == 0)
      {
        iasUnderspeedM = value[4] - '0';
        if (iasUnderspeedM == 1)
          setDisplay(6, 10);
        else
          setDisplay(6, -1);
      }
      else if (strcmp(command, "HDGM") == 0)
      {
        setDisplay(7, value[4] - '0');
        setDisplay(8, value[3] - '0');
        setDisplay(9, value[2] - '0');
      }
      else if (strcmp(command, "ALTM") == 0)
      {
        setDisplay(10, value[4] - '0');
        setDisplay(11, value[3] - '0');
        setDisplay(12, value[2] - '0');
        setDisplay(13, value[1] - '0');
        setDisplay(14, value[0] - '0');
      }
      else if (strcmp(command, "VSPM") == 0)
      {
        setDisplay(15, (value[4] - '0'));
        setDisplay(16, (value[3] - '0'));
        setDisplay(17, (value[2] - '0'));
        setDisplay(18, (value[1] - '0'));
        if (value[4]=='-')
           setDisplay(19, 17);
        else
           setDisplay(19, -1);
      }
      else if (strcmp(command, "VSPB") == 0)
      {
        vspdBlankM = value[4] - '0';
      }
      else if (strcmp(command, "CRS2") == 0)
      {
        setDisplay(20, value[4] - '0');
        setDisplay(21, value[3] - '0');
        setDisplay(22, value[2] - '0');

      }
    }

    bool isBlankDisplay(int i)
    {
      return (displayStatus[i] <= -1 ||
              (iasBlankM && (i == 3 || i == 4 || i == 5)) ||
              (vspdBlankM && (i == 15 || i == 16 || i == 17 || i == 18 || i == 19)) ||
              ((iasUnderspeedM || iasOverspeedM) && (i == 6) && (((millis() / 500) % 2) == 0)) );
    }

    void showDisplay(int i)  //+1000 to show a point,
    {
      if (!isBlankDisplay(i))
      {
        x = i;
        a = x % 2;
        x = x >> 1;
        b = x % 2;
        x = x >> 1;
        c = x % 2;
        x = x >> 1;
        d = x % 2;
        x = x >> 1;
        e = x % 2;
        x = x >> 1;
        f = x % 2;
        digitalWrite(pinEnablerM, HIGH);
        digitalWrite(pinDisplay5M, f);
        digitalWrite(pinDisplay4M, e);
        digitalWrite(pinDisplay3M, d);
        digitalWrite(pinDisplay2M, c);
        digitalWrite(pinDisplay1M, b);
        digitalWrite(pinDisplay0M, a);

        int val = displayStatus[i];
        // This is to display the point
        int dpm = 1;
        if (val >= 1000)
        {
          val = val - 1000;
          dpm = 0;
        }
        if (val >= 0 && val <= 16)
        {
          digitalWrite(pinValueAM, segmentDisplay[val][0]);
          digitalWrite(pinValueBM, segmentDisplay[val][1]);
          digitalWrite(pinValueCM, segmentDisplay[val][2]);
          digitalWrite(pinValueDM, segmentDisplay[val][3]);
          digitalWrite(pinValueEM, segmentDisplay[val][4]);
          digitalWrite(pinValueFM, segmentDisplay[val][5]);
          digitalWrite(pinValueGM, segmentDisplay[val][6]);
          digitalWrite(pinValueDPM, dpm);
          //delay(1);
        }
        digitalWrite(pinEnablerM, LOW);
      }
      else
      {
        x = i;
        a = x % 2;
        x = x >> 1;
        b = x % 2;
        x = x >> 1;
        c = x % 2;
        x = x >> 1;
        d = x % 2;
        x = x >> 1;
        e = x % 2;
        x = x >> 1;
        f = x % 2;
        digitalWrite(pinEnablerM, HIGH);
        digitalWrite(pinDisplay5M, f);
        digitalWrite(pinDisplay4M, e);
        digitalWrite(pinDisplay3M, d);
        digitalWrite(pinDisplay2M, c);
        digitalWrite(pinDisplay1M, b);
        digitalWrite(pinDisplay0M, a);
      }
      if (displayStatus[i] == 1 || displayStatus[i] == 7 || displayStatus[i] == 1016)
        delayMicroseconds(persistencyCte / 2);
      else
        delayMicroseconds(persistencyCte);
    }


    void showDisplays()
    {
      for (int i = 0; i < (numberOfDisplays); i++)
      {
        showDisplay(i);
      }
    }
};

Displays displays(PDSP0, PDSP1, PDSP2, PDSP3, PDSP4, PDSP5, PENBL, PSEGA, PSEGB, PSEGC, PSEGD, PSEGE, PSEGF, PSEGG, PSEGDP);


//*********
// LEDs
//*********
const int numberOfLeds = 17;
class Leds
{

    int ledStatus[numberOfLeds];

    int pinDisplay0M;
    int pinDisplay1M;
    int pinDisplay2M;
    int pinDisplay3M;
    int pinDisplay4M;
    int pinDisplay5M;
    int pinEnablerM;

  public:

    Leds(int display0, int display1, int display2, int display3, int display4, int display5, int enabler):
      pinDisplay0M(display0), pinDisplay1M(display1), pinDisplay2M(display2), pinDisplay3M(display3), pinDisplay4M(display4),
      pinDisplay5M(display5), pinEnablerM(enabler)
    {
      pinMode(pinDisplay0M, OUTPUT);
      pinMode(pinDisplay1M, OUTPUT);
      pinMode(pinDisplay2M, OUTPUT);
      pinMode(pinDisplay3M, OUTPUT);
      pinMode(pinDisplay4M, OUTPUT);
      pinMode(pinDisplay5M, OUTPUT);
      pinMode(pinEnablerM, OUTPUT);

      for (int i = 0; i < numberOfLeds; i++)
        ledStatus[i] = 0;
    }

    void setLed(const int ledNumber, const int value)
    {
      ledStatus[ledNumber] = value;
    }
    void setLed(const char* ledName, const char value)
    {
      int ledNumber = -1;
      if (strcmp(ledName, "ATAR") == 0)
        ledNumber = 0;
      if (strcmp(ledName, "N1ID") == 0)
        ledNumber = 1;
      if (strcmp(ledName, "SPID") == 0)
        ledNumber = 2;
      if (strcmp(ledName, "VNID") == 0)
        ledNumber = 3;
      if (strcmp(ledName, "LVLC") == 0)
        ledNumber = 4;
      if (strcmp(ledName, "HDGL") == 0)
        ledNumber = 5;
      if (strcmp(ledName, "LNAV") == 0)
        ledNumber = 6;
      if (strcmp(ledName, "VORL") == 0)
        ledNumber = 7;
      if (strcmp(ledName, "APPS") == 0)
        ledNumber = 8;
      if (strcmp(ledName, "ALTH") == 0)
        ledNumber = 9;
      if (strcmp(ledName, "VSPD") == 0)
        ledNumber = 10;
      if (strcmp(ledName, "CMDA") == 0)
        ledNumber = 11;
      if (strcmp(ledName, "CWSA") == 0)
        ledNumber = 12;
      if (strcmp(ledName, "CMDB") == 0)
        ledNumber = 13;
      if (strcmp(ledName, "CWSB") == 0)
        ledNumber = 14;
      if (strcmp(ledName, "MAS1") == 0)
        ledNumber = 15;
      if (strcmp(ledName, "MAS2") == 0)
        ledNumber = 16;

      if (ledNumber != -1)
        setLed(ledNumber, value - '0');
    }

    void showLed(int i)
    {
      if (ledStatus[i] == 1)
      {
        x = i + 32;
        a = x % 2;
        x = x >> 1;
        b = x % 2;
        x = x >> 1;
        c = x % 2;
        x = x >> 1;
        d = x % 2;
        x = x >> 1;
        e = x % 2;
        x = x >> 1;
        f = x % 2;
        digitalWrite(pinEnablerM, HIGH);
        digitalWrite(pinDisplay5M, f);
        digitalWrite(pinDisplay4M, e);
        digitalWrite(pinDisplay3M, d);
        digitalWrite(pinDisplay2M, c);
        digitalWrite(pinDisplay1M, b);
        digitalWrite(pinDisplay0M, a);
        digitalWrite(pinEnablerM, LOW);

      }
      else
      {
        x = i + 32;
        a = x % 2;
        x = x >> 1;
        b = x % 2;
        x = x >> 1;
        c = x % 2;
        x = x >> 1;
        d = x % 2;
        x = x >> 1;
        e = x % 2;
        x = x >> 1;
        f = x % 2;
        digitalWrite(pinEnablerM, HIGH);
        digitalWrite(pinDisplay5M, f);
        digitalWrite(pinDisplay4M, e);
        digitalWrite(pinDisplay3M, d);
        digitalWrite(pinDisplay2M, c);
        digitalWrite(pinDisplay1M, b);
        digitalWrite(pinDisplay0M, a);
      }
      delayMicroseconds(persistencyCte * 3);
    }


    void showLeds()
    {
      for (int i = 0; i < numberOfLeds; i++)
      {
        showLed(i);
      }
    }
};

Leds leds(PDSP0, PDSP1, PDSP2, PDSP3, PDSP4, PDSP5, PENBL);


class RotaryReader {

    int pinAM;
    int pinBM;
    unsigned long lastTimeReadM;
    unsigned long  timeM;
    int prevA;
    //char lastValueReadM[20];
    char evtM[5];

  public:
    RotaryReader(int pinA, int pinB, const char* event)
      :
      pinAM(pinA), pinBM(pinB)
    {
      lastTimeReadM = millis();
      timeM = millis();
      prevA = 0;
      //strcpy(lastValueReadM, "");
      for (int i = 0; i < 5; i++)
        evtM[i] = 0;
      strcpy(evtM, event);
      pinMode(pinAM, INPUT);
      pinMode(pinAM, INPUT);
    }

    void read()
    {
      timeM = millis();
      if ((lastTimeReadM + 1) <= timeM)
      {
        int a = digitalRead(pinAM);
        if (prevA == HIGH and a == LOW)
        {
          int b = digitalRead(pinBM);

          if (b == HIGH)
          {
            String tmpStr("EVT:");
            tmpStr += evtM;
            tmpStr += "+\7";
            Serial.print(tmpStr);
            //strcpy(lastValueReadM, "+");

          }
          else
          {
            String tmpStr("EVT:");
            tmpStr += evtM;
            tmpStr += "-\7";
            Serial.print(tmpStr);
            //strcpy(lastValueReadM, "-");

          }
        }
        prevA = a;
        lastTimeReadM = timeM;
      }

    }
};

RotaryReader rA(PCRS1A, PCRS1B, "CRS1");
RotaryReader rC(PIASA, PIASB, "IASM");
RotaryReader rE(PHDGA, PHDGB, "HDGS");
RotaryReader rG(PALTA, PALTB, "ALTS");
RotaryReader rI(PVSPA, PVSPB, "VSPS");
RotaryReader rK(PCRS2A, PCRS2B, "CRS2");

class Switch
{
    int pinM;
    int oldValM;
    unsigned long lastTimeM;
    char evtM[5];

  public:
    Switch(int pin, const char* event):
      pinM(pin), oldValM(0)
    {
      for (int i = 0; i < 5; i++)
        evtM[i] = 0;
      strcpy(evtM, event);
      lastTimeM = millis();
      pinMode(pinM, INPUT);
    }

    void read()
    {
      int val = digitalRead(pinM);

      if (val != oldValM && val == 1 && (millis() - lastTimeM > 300))
      {
        lastTimeM = millis();
        String tmpStr("EVT:");
        tmpStr += evtM;
        tmpStr += "\7";

        Serial.print(tmpStr);
      }
      oldValM = val;
    }
};


class Toggle
{
    int pinM;
    int oldValM;
    unsigned long lastTimeM;
    char evtM[5];

  public:
    Toggle(int pin, const char* event):
      pinM(pin), oldValM(0)
    {
      for (int i = 0; i < 5; i++)
        evtM[i] = 0;
      strcpy(evtM, event);
      lastTimeM = millis();
      pinMode(pinM, INPUT);
    }

    void read()
    {
      int val = digitalRead(pinM);

      if (val != oldValM && (millis() - lastTimeM > 300))
      {
        lastTimeM = millis();
        String tmpStr("EVT:");
        tmpStr += evtM;
        if (val == 1)
          tmpStr += "+";
        else
          tmpStr += "-";
        tmpStr += "\7";

        Serial.print(tmpStr);
      }
      oldValM = val;
    }
};
Switch swAtArm(PSWATARM, "ATSW");
Switch swN1(PSWN1, "N1SW");
Switch swCO(PSWCO, "COSW");
Switch swSpeed(PSWSPEED, "SPDS");
Switch swVnav(PSWVNAV, "VNAV");
Switch swSpdIntv(PSWSPDINTV, "SPDI");
Switch swLvlChg(PSWLVLCHG, "LVLC");
Switch swHdg(PSWHDG, "HDGS");
Switch swLnav(PSWLNAV, "LNAV");
Switch swVorLoc(PSWVORLOC, "VORL");
Switch swAltHold(PSWALTHOLD, "ALTH");
Switch swApp(PSWAPP, "APPS");
Switch swAltIntv(PSWALTINTV, "ALTI");
Switch swVS(PSWVS, "VSSW");
Switch swCmdA(PSWCMDA, "CMDA");
Switch swCwsA(PSWCWSA, "CWSA");
Toggle swDisengage(PSWDISENGAGE, "DIS");
Switch swCmdB(PSWCMDB, "CMDB");
Switch swCwsB(PSWCWSB, "CWSB");
Toggle swFD1(PSWFD1, "FD1");
Toggle swFD2(PSWFD2, "FD2");


const int BUFFER_SIZE = 3000;

class SerialBuffer
{
  public:

    byte serialBuffer[BUFFER_SIZE];

    int readingPtr;
    int writingPtr;


    SerialBuffer():
      readingPtr(0), writingPtr(0)
    {
      for (int k = 0; k < BUFFER_SIZE; k++)
      {
        serialBuffer[k] = 0;
      }
    }

    bool available()
    {
      while (Serial.available() > 0)
      {
        serialBuffer[writingPtr] = Serial.read();
        writingPtr++;
        writingPtr %= BUFFER_SIZE;
      }
      return readingPtr != writingPtr;
    }

    int read()
    {
      available();
      if (readingPtr != writingPtr)
      {
        int value = serialBuffer[readingPtr];
        readingPtr++;
        readingPtr %= BUFFER_SIZE;
        return value;
      }
      return -1;
    }
    int size()
    {

      if (writingPtr >= readingPtr)
        return writingPtr - readingPtr;
      else
        return writingPtr + BUFFER_SIZE - readingPtr;
    }

};


void setup () {

  Serial.begin (38400, SERIAL_8O2);
  pinMode(13, OUTPUT);

}

int i = 0;
SerialBuffer serialBuffer;


void loop ()
{

  for (int i = 0; i < 24; i++)
  {

    //********************************
    // Write 7 segment displays
    //********************************
    displays.showDisplay(i);

    //********************************
    // Write 7 segment displays
    //********************************
    leds.showLed(i);

    //********************************
    // Read Rotary Encoders
    //********************************
    rA.read();
    rC.read();
    rE.read();
    rG.read();
    rI.read();
    rK.read();
  }

  //********************************
  // Read inputs
  //********************************
  swAtArm.read();
  swN1.read();
  swCO.read();
  swSpeed.read();
  swVnav.read();
  swSpdIntv.read();
  swLvlChg.read();
  swHdg.read();
  swLnav.read();
  swVorLoc.read();
  swAltHold.read();
  swApp.read();
  swAltIntv.read();
  swVS.read();
  swCmdA.read();
  swCwsA.read();
  swDisengage.read();
  swCmdB.read();
  swCwsB.read();
  swFD1.read();
  swFD2.read();

  //********************************
  // Read Serial incoming events
  //********************************
  if (serialBuffer.available())
  {
    //Serial.println(serialBuffer.size());
    int incomingByte = serialBuffer.read();
    if (incomingByte == 'l')
    {
      Serial.print("Converted: ");

      int counter = 0;
      int byteRead = 0;

      char str[3] = {0, 0, 0};
      while (counter < 2) // 2 chars to define the led
      {
        if ((byteRead = serialBuffer.read()) != -1)
          str[counter++] = byteRead;
      }
      int ledToChange = atoi(str);
      Serial.print(ledToChange);
      leds.setLed(ledToChange, 1);
    }
    else if (incomingByte == 'd')
    {
      Serial.print("Converted Display: ");
      char str[4] = {0, 0, 0, 0};
      int counter = 0;
      int byteRead = 0;
      while (counter < 2) // 2 chars to define the display
      {
        if ((byteRead = serialBuffer.read()) != -1)
          str[counter++] = byteRead;
      }
      int displayToChange = atoi(str);
      Serial.print(displayToChange);
      char strVal[2] = {0, 0};
      counter = 0;
      while (counter < 1) // 1 chars to define the value
      {
        if ((byteRead = serialBuffer.read()) != -1)
          strVal[counter++] = byteRead;
      }

      int valToSet = atoi(strVal);
      Serial.print("\nValue: ");
      Serial.println(valToSet);
      displays.setDisplay(displayToChange, valToSet);
    }
    else if (incomingByte == 'D')
    {
      int counter = 0;
      int byteRead = 0;
      char command[6] = {0, 0, 0, 0, 0, 0};
      while (counter < 4) // 4 chars to define the command
      {
        if ((byteRead = serialBuffer.read()) != -1)
          command[counter++] = (char)byteRead;
      }
      counter = 0;
      char value[6] = {0, 0, 0, 0, 0, 0};
      while (counter < 5) // 5 digits to define the value
      {
        if ((byteRead = serialBuffer.read()) !=  -1)
          value[counter++] = (char)byteRead;
      }
      displays.setDisplay(command, value);
    }
    else if (incomingByte == 'L')
    {
      int counter = 0;
      int byteRead = 0;

      char ledName[6] = {0, 0, 0, 0, 0, 0};
      while (counter < 4) // 4 chars to define the command
      {
        if ((byteRead = serialBuffer.read()) != -1)
          ledName[counter++] = byteRead;
      }
      counter = 0;
      char value = '0';
      while (counter < 1) // 1 char to define the value
      {
        if ((byteRead = serialBuffer.read()) != -1)
        {
          value = byteRead;
          counter++;
        }
      }
      leds.setLed(ledName, value);
    }
    else if (incomingByte == 't')
    {

      int counter = 0;
      int byteRead = 0;

      char testName[6] = {0, 0, 0, 0, 0, 0};
      while (counter < 4) // 4 chars to define the test name
      {
        if ((byteRead = serialBuffer.read()) != -1)
          testName[counter++] = byteRead;
      }
      Serial.print("ANSWER:");
      Serial.print(testName);
      Serial.print(" SUM");
      Serial.println(testName[0] + testName[1] + testName[2] + testName[3]);
    }

  }
};

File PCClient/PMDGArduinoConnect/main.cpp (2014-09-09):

//------------------------------------------------------------------------------
//
//  PMDG 737NGX external connection sample 
// 
//------------------------------------------------------------------------------

#include "MainFactory.h"



/*
#include "Logger.h"
#include "PMDG_NGX_SDK.h"

#include <windows.h>
#include <tchar.h>
#include <stdio.h>
#include <strsafe.h>
*/
//[STAThreadAttribute]
//[STAThread]
int main(array<System::String ^> ^args)
{

	/*Project2::MyForm^ myForm = gcnew Project2::MyForm();
	myForm->Show();
	*/
	//in the main function
	System::Windows::Forms::Application::EnableVisualStyles();
System::Windows::Forms::Application::SetCompatibleTextRenderingDefault(false);

// Create the main window and run it
System::Windows::Forms::Application::Run(MainFactory::getMainForm());
}

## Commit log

2014-08-30 Back to normal. Now it works fine. Serial 8B Odd Par and 2StopBits
    Still looses messages
    [ArduinoVirtualCockpit.ino, MainForm.h]
2014-09-04 Arduino buffer for serial port.
    Send commands from Processing to Arduino at maximum speed
2014-09-04 Buffer Problems fixed Now every data from processing to Arduino gets correctly
    [ArduinoVirtualCockpit.ino, MainForm.h]
2014-09-09 AT Arm led works by using FSUIPC
2014-09-14 PCB Boards started in Eagle and Fritzing
    [InputBoard.fzz, InputOutputBoard.fzz, Output Board.fzz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]
2014-09-14 Couple of libraries added. This is not good practice but we need them
2014-09-14 Added git ignore for pcb files
2014-09-18 Blank display for IAS and updates in PCB boards
    [OutputBoard.brd, OutputBoard.sch]
2014-09-28 New InputBoard and some modifications to OutputBoard
    [InputBoard.brd, InputBoard.sch, OutputBoard.brd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]
2014-10-09 PCB Modified with proper flip flop 74 273 and ground fill
    [OutputBoard.brd, OutputBoard.sch]
2015-03-15 Eagle PDF files removed
    Conflicts:
    PCB/Eagle/OutputBoard/OutputBoardBottom.pdf
    PCB/Eagle/OutputBoard/OutputBoardTop.pdf
    [OutputBoard.brd, OutputBoard.sch]
2015-03-15 Possible routing for two sides and full board
    PCB/Eagle/OutputBoard/OutputBoard.brd
    PCB/Eagle/OutputBoard/OutputBoard.sch
    PCB/Eagle/OutputBoard/eagle.epf
    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
    [OutputBoard.brd, OutputBoard.sch]
2015-03-15 PCB files ready for print, with polygons but no VCC or GND. Good routing
    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
    [OutputBoard.brd, OutputBoard.sch]
2015-03-15 CNC started
    [Sketch.skp]
2015-03-15 Changes to CNC model
    [Sketch.skp]
2015-03-15 Modifs to CNC file
    [Sketch.skp]
2015-03-15 More Modifs
    [Sketch.skp]
2015-03-15 More updates to CNC (Minor: couplers)
    [Sketch.skp]
2015-03-15 CNC: Better hierarchy, more annotations and more standard measurements
    [Sketch.skp]
2015-03-15 Updates in CNC: Ball Bearings
    [Sketch.skp]
2015-03-15 Some minor adjustments on anotations
    [Sketch.skp]
2015-03-15 PDF Files added for printing data of CNC
2015-03-15 Change in view
    [Sketch.skp]
2015-03-15 New output board based on serial controllers
    [OutputBoard.brd, OutputBoard.sch]
2015-03-15 Fixes due to missing blob in repository
    THe eagle files for Output Board since 2014-10-16 22:07:17 may be wrong in history
    [OutputBoard.brd, OutputBoard.sch]
2015-03-21 Commenting the Arduino file
2015-03-29 Some more input & output boards
    [InputBoard.brd, InputBoard.sch, OutputBoard.sch]
2015-05-15 Input Board in DesignSpark ready for milling
    [InputBoard.sch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]
2015-07-12 Gcode for Input board from DesignSpark
    [InputBoard.sch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]
2016-01-31 FSUIPC removed as it is no longer needed
    Adapted to new version of VS Studio
    [MainForm.h]
2016-03-13 Finally a flow to convert to gcode from Inkscape
2016-10-02 Handling couple of messages in simconnect loop
2016-10-02 Negative prints in PCB for Input Board added
    [InputBoard - Bottom Copper.gbr]
2016-10-19 Thicker tracks, pads and vias in InputBoard
    [InputBoard.sch]
2016-10-29 Guide for getting good PCBs with dry film
